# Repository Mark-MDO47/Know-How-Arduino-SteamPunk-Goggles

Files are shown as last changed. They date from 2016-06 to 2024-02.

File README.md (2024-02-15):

# Know-How-Arduino-SteamPunk-Goggles

Adapted from two episodes of TWIT-TV Know How
- Episode 186: https://twit.tv/shows/know-how/episodes/186?autostart=false
- Episode 187: https://twit.tv/shows/know-how/episodes/187?autostart=false

**Table Of Contents**
* [Top](#know\-how\-arduino\-steampunk\-goggles "Top")
* [Pictures](#pictures "Pictures")
* [Attribution](#attribution "Attribution")
* [Software changes from KnowHow](#software-changes-from-knowhow "Software changes from KnowHow")
* [UPDATE:](#update "UPDATE:")
* [FURTHER UPDATE:](#further-update "FURTHER UPDATE:")

## Pictures
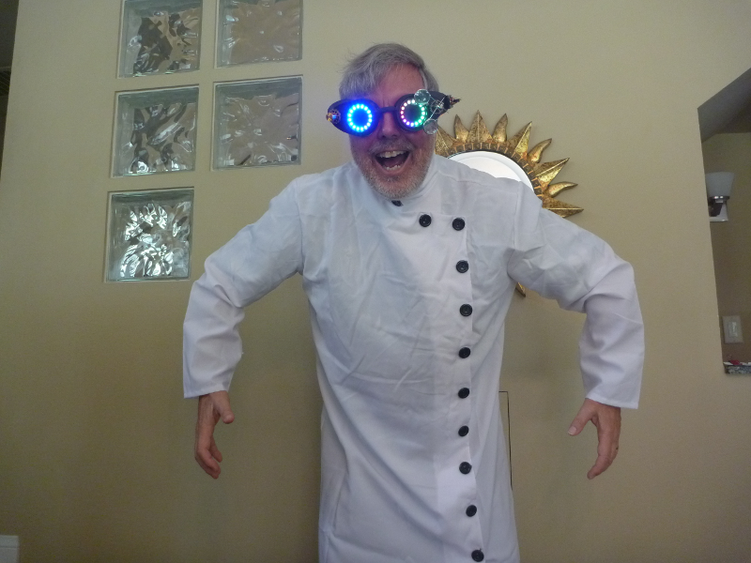
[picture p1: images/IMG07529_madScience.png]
Mad Science is improved when wearing steampunk goggles

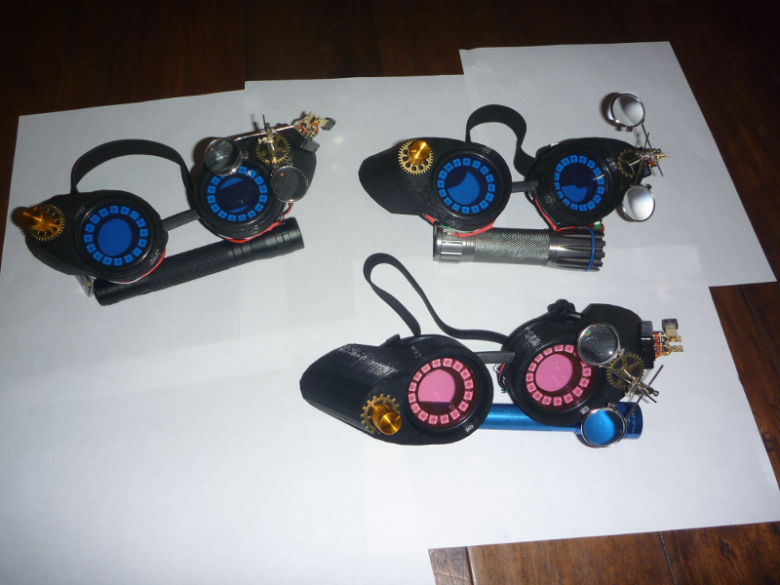
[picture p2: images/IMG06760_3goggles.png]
Built three steampunk goggles - two for friends


## Attribution
Major kudos to Fr. Robert Ballecer and Bryan Burnett for their steampunk goggles project and for pointing me to the FastLED library

Major kudos to Daniel Garcia and Mark Kriegsman for the FANTASTIC FastLED library and examples!!!
https://github.com/FastLED/FastLED

## Software changes from KnowHow

You can see a video of the goggles running through all its patterns at https://youtu.be/VJ-WH86G7Pg

I made one of the potentiometer-selectable patterns cycle or rove through all the patterns one by one.

Then I noticed the code was originally based on some brilliant FastLED patterns that were designed for linear light strips but of course the goggles use two circular rings.

In particular the “sinelon” pattern seemed like it would benefit from remapping the LEDs in a non-linear order. I made the moving light go in a figure-8 pattern between the goggles.

I added a new racetrack” pattern which does two sinelon “cars” moving at slightly different rates.

I also added a “spinner” pattern with four dots per side that spin, and made one side spin back and forth and the other side spin constantly in one direction.

Finally I looked back at other fantastic code samples from FastLED and adapted the “Fire2012” pattern to two circular rings.
https://github.com/FastLED/FastLED/blob/master/examples/Fire2012WithPalette/Fire2012WithPalette.ino

This code is just for fun; not trying to make it an example of how to code in serious applications.

## UPDATE:
See post on TWIT Know-How group in Google Plus: https://plus.google.com/100452347452995185114
See the mention received on TWIT.TV Know-How Episode 225: https://twit.tv/shows/know-how/episodes/225?autostart=false
Thanks Fr. Robert Ballecer and Bryan Burnett for the shout-out!!! Sorry my Google Plus post was such a jaw buster!

Later - Google Plus is no more so that link doesn't work

## FURTHER UPDATE:
For a description of differences between the this build and the KnowHow build (other than software changes above), see
* https://github.com/Mark-MDO47/Know-How-Arduino-SteamPunk-Goggles/blob/master/KnowHowBuildInstructions.md

For a schematic-style wiring diagram of this build, see the KiCad directory or
* https://github.com/Mark-MDO47/Know-How-Arduino-SteamPunk-Goggles/blob/master/SteamPunkGoggles_Wiring.pdf

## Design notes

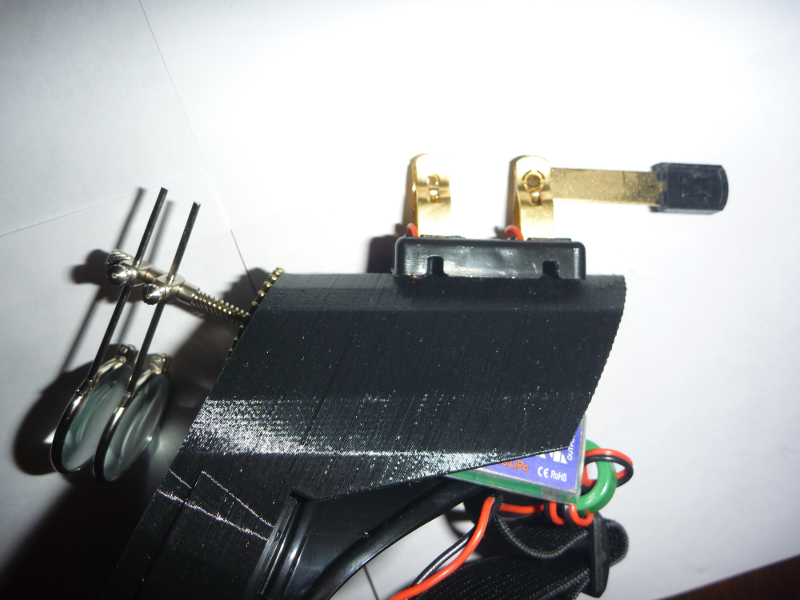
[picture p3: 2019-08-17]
images/IMG06764_detailSwitch.png

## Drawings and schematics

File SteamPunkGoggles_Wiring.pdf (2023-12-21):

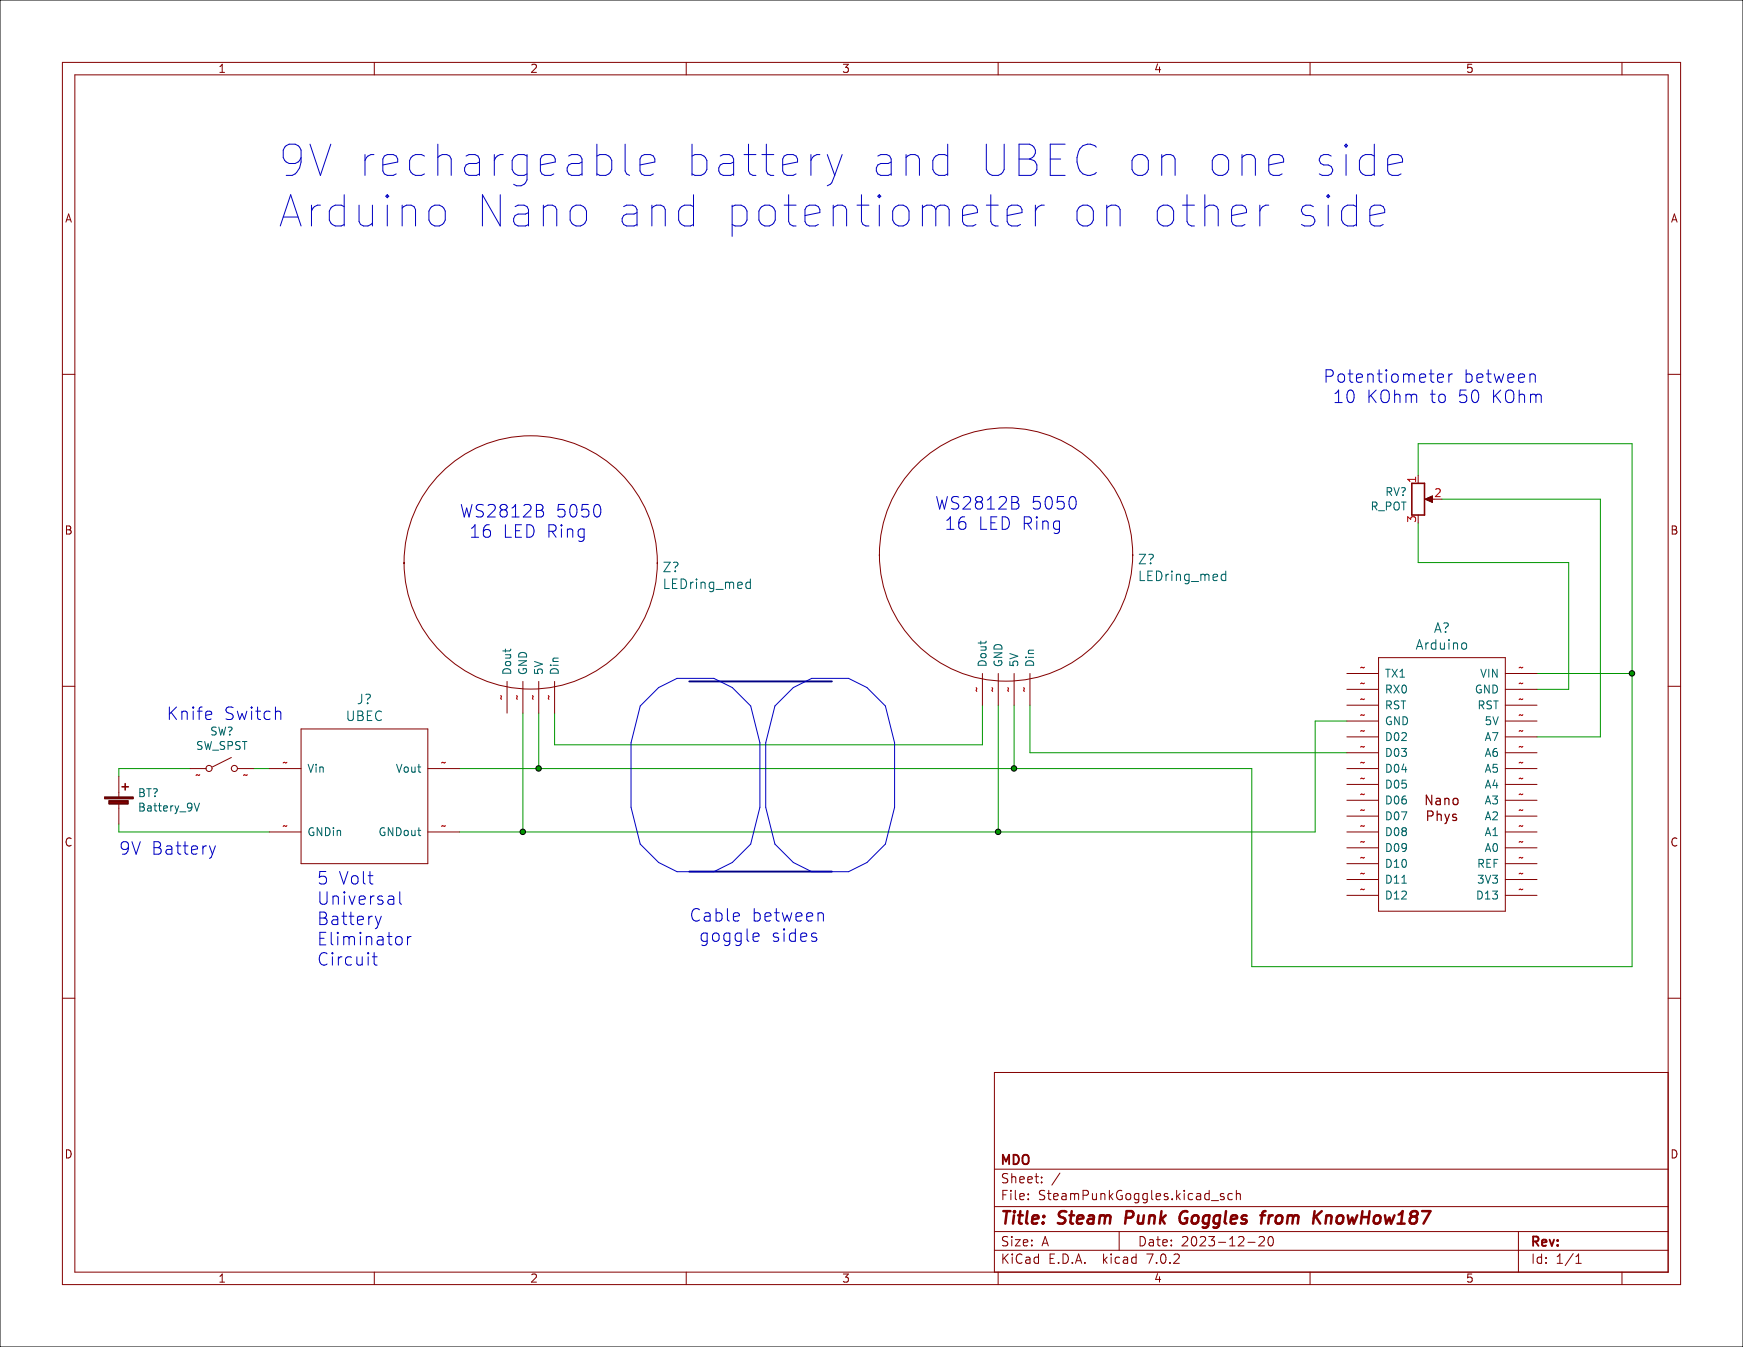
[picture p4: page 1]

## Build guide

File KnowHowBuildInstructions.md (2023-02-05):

# Differences MDO build versus KnowHow build

There are a few differences in my build versus the KnowHow build
- I used a 9V rechargeable battery
- I added a knife switch to power on/off - homage to Frankenstein
- I put all the 5V connections to the Arduino on the 5V pin (no connect for VIN)
- I connected ground to the Arduino REF pin - this gives better performance from the analog input
- I only used one gear for the potentiometer instead of two

Below text is instruction from TWIT-TV KnowHow

# Goggle Wiring Instructions from TWIT-TV Know How 186:

These are the parts you'll need to order for our Steampunk Goggles Build

[MDO - Note that these prices are from 2016]

* Vintage Steampunk Welding Goggles $7.99
* GraceAngie 40Pcs Bronze Alloy Roung Clock Watch gears $6.99
* Magnifying Loupe $6.75
* Arduino Nano (Atmega 328P) $2.19
* WS2812 16-Bit RGB LED Ring ($3.17 x 2) $6.34
* 30AWG Silicone Wire ($1.00 x 3) [Red, Black, Blue] $3.00
* 600mah batteries + Charging harness $18.00

Total $51.26

You'll also need a 3D Printer that can print the following parts
* Steampunk Googles Frame (Right Side)
* Steampunk Goggles Frame (Left Side)
* Steampunk Goggles LED Holder (x2)

Tools and supplies
* 3D Printer
* Dremel (or other drilling tool)
* Hot Glue Gun
* Soldering Kit
* Pliers, Screwdrivers
* Heat Shrink Tubing (Black)

Instructions:
* Disconnect one of the eye cups from the bridge strap
* Drill a small rat hole at the base of each nose-cutout. (Big enough for 6 strands of 30awg silicone wire
* Cut the following pieces of 30awg Silicone Wire -- 2 x 6" Red -- 1 x 8" Red -- 2 x 6" Black -- 1 x 8" Black -- 1 x 6" White -- 1 x 8" White
* Strip and tin all your Silicone wires
* Cut a 3/4" long piece of 1/4" Black Heat Shrink tubing
* Run the 3, 8" lengths through the heat shrink tubing, then push the tubing & wires over the exposed bridge strap
* Reconnect both cups to the bridge strap
* Run the 3, 8" lengths into the left cup rat-hole.
* Solder the following: -- Black to any "GND" pad -- Red to any "VCC" pad -- White to "IN" pad
* Run 1 x 6" black and 1 x 6" red into the left cup rat-hole
* Solder the following: -- Black to the remaining "GND" pad -- Red to the remaining "VCC" pad
* Solder the black and red wires to a battery connector from the charging harness
* Pull back the slack wire from the left cup
* Run the other side of the 8" wires into the rat-hole on the right cup.
* Solder the following: -- Black to any "GND" pad -- Red to any "VCC" pad -- White to the "OUT" pad
* Run the remaining 6" black, red and white wires into the right-cup rat-hole.
* Solder the following: -- Black to the remaining "GND" pad -- Red to the remaining "VCC" pad -- White to the "In" pad
* Solder the other ends of those wires to the Arduino: -- Black to "GND" -- Red to "VIN" -- White to "D3"

# Goggle Integration Instructions from from TWIT-TV Know How 187:

Instructions
* Solder 30awg black/red (ground/voltage) wires to the outside pins of the potentiometer
* Solder a single 30awg blue or white wire to the inside pin of the pot
* Solder the black wire to an arduino GND through-hole
* Solder the red wire to the arduino 5v through-hole
* Solder the blue/white wire to the arduino Analog 7 through-hole
* Insulate your Arduino assembly with a strip of 1-1/4" clear heat-shrink.
* Insert the LED retention rings into each cup, making sure to keep the wires in the cutout
* Install the potentiometer into the 6mm hole in the right cup, lighing up the support peg with the indent
* Shave down the center hole of two brass gears so that they will fit around the pot shaft.
* Place the brass gear over the pot shaft and fasten it with a washer and the mounting nut.
* Insert the right cup into the right-frame, making sure to line up the bridge strap with the cutout in the frame piece, while holding back the wires so that they'll be hidden by the frame.
* Using a piece of double-sided foam tape, secure the arduino to the inside of the right frame. 13. Remove the mounting nut, clips and clip spring from the magnifying loupe.
* Insert the loupe pole through a brass gear, then insert it into the 2mm mounting hole in the left frame.
* Secure the loupe with the mounting nut, tightening it until the loupe lenses are held in tension.
* Run the battery harness through the hole at the bottom of the battery plate in the left frame piece.
* Insert the left cup into the left frame, once again making sure that the wires are covered by the frame.
* Programming We need to add the code that allows us to use the potentiometer to control which animation is being displayed.

Things to Remember
* We're using the "100 lines" code as the basis of our sketch
* We soldered the wiper (the pin that sends variable voltage depending on the position of the pot) to Analog 7
* The data line going to our LED rings is soldered to Digital 3. We have 32 LEDs (16 + 16) [MDO correction pin 3]

Things that we changed in the Code
* DATA_PIN is set to "3"
* NUM_LEDS is set to "32"
* Brightness is set to "100"
* We added "Serial.begin(9600);" to the setup so we can get feedback from the Arduino
* In "loop()", we changed the last line 
  * "EVERY_N_SECONDS( 10 ) { nextPattern();"
* to: -- 
  * "EVERY_N_Seconds ( .5 ) { pattern();"
* By bumping the "EVERY_N_SECONDS" down to .5, it means that the Arduino will call the "pattern()" function ever half-second, instead of checking every 10 seconds
* We created the function "pattern()" to check the status of the Analog pot and turn it into a value that will set "gCurrentPatternNumber" to a value between 0-5
* We added a function and an array entry for blanking the ring.

The "pattern" routine
* void pattern()
* { int aRead = analogRead(7); // This checks the pot connected to Analong Pin 7 and gives us a value between 0-1024
*   int PatChoice = map(aRead, 0, 1020, 0, 6); // This maps the value of the pot from 0-1020 to a value between 0-5
*   Serial.print(aRead); // debug -- Sends the value of the pot to the serial port
*   Serial.print(""\t""); // debug -- Sends a tab
*   Serial.println(PatChoice); // debug -- Sends the remapped value to the serial port, then breaks into a new line
*   gCurrentPatternNumber = PatChoice; // Sent the animation value
* }

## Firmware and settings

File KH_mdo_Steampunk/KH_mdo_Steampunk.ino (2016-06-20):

#include "FastLED.h"

// FastLED "100-lines-of-code" demo reel, showing just a few 
// of the kinds of animation patterns you can quickly and easily 
// compose using FastLED.  
//
// This example also shows one easy way to define multiple 
// animations patterns and have them automatically rotate.
//
// -Mark Kriegsman, December 2014


// The Fire2012 code is based on 2016-06-01 version of
//   https://github.com/FastLED/FastLED/blob/master/examples/Fire2012WithPalette/Fire2012WithPalette.ino

// Mark Olson 2016-06
// adapted from TWIT-TV Know How 187: https://twit.tv/shows/know-how/episodes/187?autostart=false
//     major kudos to Fr. Robert Ballecer and Bryan Burnett for their steampunk goggles project
//             and for pointing me to the FastLED library
//     major kudos to Daniel Garcia and Mark Kriegsman for the FANTASTIC FastLED library and examples!!!
//
// I consider these to be my "mad scientist" goggles...
//
// As in the KH original,  patterns can be selected via the potentiometer. If the potentiometer is set 
//     all the way clockwise, then it "roves" through the patterns (most of them).
// I added a knife-switch on/off control (mad scientist) so I don't use the blank() pattern.
//     Knife switch looks cool!
//
// I adapted the sinelon() pattern to know about the dual-ring LED arrangement; it now does a figure-8
// I added a few patterns; all of them dual-ring aware:
//     racetrack() - like sinelon() but with two non-synchronized "race cars"
//     spinner() - four color spots with RH rotating constant speed and LH rotating back & forth in pattern
//     Fire2012WithPalette() - fire pattern (see Fire2012 above) distributed symmetrically about the nose.
//         When "roving" through the patterns, uses the HEAT color scheme. When pattern statically selected,
//         cycles through color schemes with both sides same scheme (looks better than different schemes).
//         When "roving", both sides move symmetrically around the ring slowly.
//         When pattern statically selected, RH side moves as above but LH side rotating back and forth.

#if FASTLED_VERSION < 3001000
#error "Requires FastLED 3.1 or later; check github for latest code."
#endif

#define DATA_PIN    3
#define LED_TYPE    WS2812
#define COLOR_ORDER GRB
#define NUM_LEDS    32
CRGB leds[NUM_LEDS];

// MDO some more definitions for fancy lights
#define HALF_LEDS (NUM_LEDS/2)
#define QUARTER_LEDS (NUM_LEDS/4)
#define EIGHTH_LEDS  (NUM_LEDS/8)

// MDO analog definitions
#define ANLG_PIN  7
#define ANLG_ROVING 1000 // anything >= this gives the roving pattern

#define BRIGHTNESS         100
#define FRAMES_PER_SECOND  120


#define NUMOF(a) (sizeof((a)) / sizeof(*(a)))

// COOLING: How much does the air cool as it rises?
// Less cooling = taller flames.  More cooling = shorter flames.
// Default 55, suggested range 20-100 
#define COOLING  80

// SPARKING: What chance (out of 255) is there that a new spark will be lit?
// Higher chance = more roaring fire.  Lower chance = more flickery fire.
// Default 120, suggested range 50-200.
#define SPARKING 100

CRGBPalette16 gPal_fire;
CRGBPalette16 gPal_fire_alt;

byte g_alt_use_for_lh = 0; // set to 1 to use alt color scheme and mapping for LH

// choose the fire color scheme
#define FIRE_COLOR_SCHEME_HEAT 1 // the FastLED built-in HeatColors_p
#define FIRE_COLOR_SCHEME_BRW  2 // a simplified three-step gradient, from black to red to white
#define FIRE_COLOR_SCHEME_BRYW 3 // a gradient from black to red to yellow to white
#define FIRE_COLOR_SCHEME_BLUE 4 // a similar gradient, but in blue colors rather than red ones
#define FIRE_COLOR_SCHEME_MDO  5 // Mark's attempt to tune fire colors to his LED rings
#define FIRE_COLOR_SCHEME_GRN  6 // Mark's attempt at a green pattern
#define FIRE_COLOR_SCHEME_DYN  7 // a dynamic palette
#define PLAYFIRE_COLOR_SCHEME_MIN  FIRE_COLOR_SCHEME_BRYW // minimum to cycle through
#define PLAYFIRE_COLOR_SCHEME_MAX  FIRE_COLOR_SCHEME_GRN  // maximum to cycle through inclusive
static uint8_t g_color_scheme = FIRE_COLOR_SCHEME_HEAT; // HEAT is used when roving through patterns
static uint8_t g_color_scheme_alt = FIRE_COLOR_SCHEME_BRYW; // alternate scheme for LH side

// #define DEBUG_MAP // print LED mapping on serial monitor each time the arrangement is set
#define DEBUG_POT // print potentiometer setting on serial monitor each time the arrangement is read

// for symmetry of glasses - two round LED strings
// this mapping can be used with the Fire2012 code and with other effects
static byte g_lin2circ_arrange[NUM_LEDS]; // maps linear index to double circle
static byte g_lin2circ_arrange_alt[NUM_LEDS]; // maps linear index to double circle - alternate copy
static byte g_arrange_sym = 1; // 1 = patterns are symmetrical left-to-right and up-to-down
                        // 0 = patterns same side and same top/bottom on both
static char g_arrange_sym_mult = (1-(g_arrange_sym*2)); // -1 for sym, +1 for same)
static int g_arrange_rotate_modulus = 60; // default how many "show()" between rotates;
static int g_arrange_rot_count = 0; // used if we rotate point of fire
static byte g_arrange_rot_rh = 12; // used if we rotate point of fire; map linear 0 to this
                         // 12 means to "nose" of glasses (20 for LH side)
                         //  8 means top of glasses
                         //  4 means outside of glasses
                         //  0 means bottom of glasses
static byte g_arrange_rot_lh = 20; // used if we rotate point of fire
                        // ((g_arrange_rot_rh + HALF_LEDS - g_arrange_sym * QUARTER_LEDS) % HALF_LEDS)
// #define ARRANGE_CAL_RING // display "red" LED on fire point each time the arrangement is set

// example: g_arrange_sym 1 and g_arrange_rot_rh 12 and g_arrange_rot_lh 20
// in this one fire burns from nose of glasses to edges





void setup() {
  delay(3000); // 3 second delay for recovery
  
  Serial.begin(9600);
  
  // tell FastLED about the LED strip configuration
  FastLED.addLeds<LED_TYPE,DATA_PIN,COLOR_ORDER>(leds, NUM_LEDS).setCorrection(TypicalLEDStrip);
  //FastLED.addLeds<LED_TYPE,DATA_PIN,CLK_PIN,COLOR_ORDER>(leds, NUM_LEDS).setCorrection(TypicalLEDStrip);

  // set master brightness control
  FastLED.setBrightness(BRIGHTNESS);

  // initialize the linear to circular mapping
  init_lin2circ_arrange(g_lin2circ_arrange, g_arrange_rot_lh, g_arrange_rot_rh, g_arrange_sym, g_arrange_sym_mult);

  // initialize the Fire palette
  Fire2012WithPalette_setup(gPal_fire, g_color_scheme);
} // end setup()


// List of patterns to cycle through.  Each is defined as a separate function below.
typedef void (*SimplePatternList[])();
SimplePatternList gPatterns = { blank, rainbow, spinner, rainbowWithGlitter, confetti, sinelon, juggle, bpm, Fire2012WithPalette, racetrack };

uint8_t gCurrentPatternNumber = 0; // Index number of which pattern is current
uint8_t gRovingPatternNumber = 0; // MDO roving pattern number if roving selected
uint16_t gRovingCount = 0; // MDO roving count to change
uint8_t g_IamRovingThePattern = 0; // MDO - =1 if we are roving the pattern
uint8_t gHue = 0; // rotating "base color" used by many of the patterns
  
void loop()
{
  // Call the current pattern function once, updating the 'leds' array
  gPatterns[gCurrentPatternNumber]();

  // send the 'leds' array out to the actual LED strip
  FastLED.show();  
  // insert a delay to keep the framerate modest
  FastLED.delay(1000/FRAMES_PER_SECOND); 

  // do some periodic updates
  EVERY_N_MILLISECONDS( 10 ) { gHue++; } // slowly cycle the "base color" through the rainbow
  EVERY_N_SECONDS( .5 ) { pattern(); } // change patterns periodically
} // end loop()

void pattern()
{
  int aRead = analogRead(ANLG_PIN); // This checks the pot connected to Analog Pin 7 and gives us a value between 0-1024
  // MDO note: we have on/off switch so don't need zero. Leave in place though
  int PatChoice = map(aRead, 0, ANLG_ROVING, 1, NUMOF(gPatterns)); // This maps the value of the pot from 0-1023 to a value between 1 to last pattern num
  g_IamRovingThePattern = 0;
  if (aRead > (ANLG_ROVING-1)) 
  { // MDO fixes some oscillation at the high end
    g_IamRovingThePattern = 1;
    PatChoice = gRovingPatternNumber + 2;
  }

#ifdef DEBUG_POT
  Serial.print(aRead); // debug -- Sends the value of the pot to the serial port
  Serial.print("\t");  // debug -- Sends a tab
  Serial.println(PatChoice);  // debug -- Sends the remapped value to the serial port, then breaks into a new line
#endif // DEBUG_POT

  gCurrentPatternNumber = PatChoice; // Set the animation value
  rove_pattern();

  // rotate the linear to circular fire points
  loop_lin2circ_arrange();

}  // end pattern()

void rove_pattern() // MDO rove through pattern numbers
{
  gRovingCount += 1;
  if (gRovingCount >=511)
  {
    gRovingCount = 0;
    gRovingPatternNumber = ((gRovingPatternNumber + 1) % (NUMOF(gPatterns)-2)); // MDO +2 to get a pattern
    // rainbow and rainbow with glitter are so close just doing glitter
  }
} // end rove_pattern()

static uint32_t mdoResetTime = 0;

uint32_t mdo_millisecond_timer()
{
  return millis() - mdoResetTime;
} // end mdo_millisecond_timer()

void mdo_millisecond_timer_reset()
{
  mdoResetTime = millis();
} // end mdo_millisecond_timer_reset()

void blank()
{
  fadeToBlackBy( leds, NUM_LEDS, 20); // This gives the goggles an "off" position
} // end blank()

void rainbow()
{
  // FastLED's built-in rainbow generator
  fill_rainbow( leds, NUM_LEDS, gHue, 7);
} // end rainbow()

void rainbowWithGlitter() 
{
  // built-in FastLED rainbow, plus some random sparkly glitter
  rainbow();
  addGlitter(80);
} // end rainbowWithGlitter()

void addGlitter( fract8 chanceOfGlitter) 
{
  if( random8() < chanceOfGlitter) {
    leds[ random16(NUM_LEDS) ] += CRGB::White;
  }
} // end addGlitter()

void confetti() 
{
  // random colored speckles that blink in and fade smoothly
  fadeToBlackBy( leds, NUM_LEDS, 10);
  int pos = random16(NUM_LEDS);
  leds[pos] += CHSV( gHue + random8(64), 200, 255);
} // end confetti()

void sinelon()
{
  // a colored dot sweeping back and forth, with fading trails
  // Mark Olson 2016-05 - make it do figure-8 by using calcpos_figure8
  fadeToBlackBy(leds, NUM_LEDS, 20);
  int pos = beatsin16(13,0,4*NUM_LEDS);
  pos = calcpos_figure8(pos);
  leds[pos] += CHSV( gHue, 255, 192);
} // end sinelon()

// Mark Olson 2016-05
//   racetrack shows two "cars" racing on a figure-8 racetrack
//   The two cars are out of sync with each other so effect appears
//   chaotic (although actually predictable)
void racetrack()
{
  // clear the screen a bit so not too busy
  fadeToBlackBy(leds, NUM_LEDS, 120);
  
  int pos = beatsin16(13,0,4*NUM_LEDS);
  pos = calcpos_figure8(pos);
  leds[pos] += CHSV( gHue, 255, 192);

  pos = beatsin16(14,0,4*NUM_LEDS);
  pos = calcpos_figure8(pos);
  leds[pos] += CHSV( gHue+128, 255, 192);
} // end racetrack()

int calcpos_figure8(int pos)
{
  // Mark Olson 2016-05
  //   tilt both circles 1/4 but in opposite directions
  //   used to make figure 8 for racetrack
  // a different implementation can be found in the routines with lin2circ in the name
  pos %= NUM_LEDS;
  if (pos >= HALF_LEDS) {
    pos = (pos - EIGHTH_LEDS) % HALF_LEDS;
    pos = NUM_LEDS - 1 - pos;
  } else {
    pos =(pos + 3*EIGHTH_LEDS - 1) % HALF_LEDS;
  }
  return(pos);
} // end calcpos_figure8()


static int g_spin_color_mode = 3; // 0=simple, 1=lava, 2=party, 3=party/lava
CRGB spin_colors(byte iter, int led)
{
  // Mark Olson 2016-05
  // used by the spinner routine to cycle through colors
  // I should probably get my act together and merge all the palettes, but I
  //    have not run out of memory yet...
  static CRGB some_spin_colors[4] = { CRGB::White, CRGB::Red, CRGB::Navy, CRGB::Green };
  static CRGBPalette16 party_palette = PartyColors_p;
  static CRGBPalette16 lava_palette = LavaColors_p;

  int my_spin_color_mode = g_spin_color_mode;
  if (my_spin_color_mode >= 3) {
    my_spin_color_mode -= (led/HALF_LEDS) + 1;
  }

  switch (my_spin_color_mode) {
    case 1: // lava
      return ColorFromPalette(lava_palette, gHue-led+(iter*59), led-gHue+(iter*59));
      break;
    case 2: // party
      return ColorFromPalette(party_palette, gHue-led+(iter*59), led-gHue+(iter*59));
      break;

    default:
    case 0: // simple
      return some_spin_colors[iter & 0x3];
      break;
  }
} // end spin_colors()

#define SPIN_INTERVAL 4
void spinner()
{
  // Mark Olson 2016-05
  //   this puts four dots on the screen and spins them
  //   the right hand side goes clockwise at constant speed
  //   the left hand side goes back and forth at varying speed

  // clear the screen a bit so not too busy
  fadeToBlackBy(leds, NUM_LEDS, 100);

  int pos1 = (mdo_millisecond_timer() / 50) & 511;
  int pos2 = beatsin16(13,0,64);

  byte dothue = 0;
  int tmp = 0;
  for (int i = 0; i < HALF_LEDS; i += SPIN_INTERVAL)
  {
     tmp = (pos1+i) % HALF_LEDS;
     leds[tmp] |= spin_colors(dothue, tmp);
     // dothue += 32;
     tmp = (pos2+i+SPIN_INTERVAL/2) % HALF_LEDS;
     tmp = HALF_LEDS-tmp-1; // reverse direction
     leds[tmp+HALF_LEDS] |= spin_colors(dothue, tmp+HALF_LEDS);
     dothue += 1;
  }
} // end spinner()

void bpm()
{
  // colored stripes pulsing at a defined Beats-Per-Minute (BPM)
  uint8_t BeatsPerMinute = 62;
  CRGBPalette16 palette = PartyColors_p;
  uint8_t beat = beatsin8( BeatsPerMinute, 64, 255);
  for( int i = 0; i < NUM_LEDS; i++) { //9948
    leds[i] = ColorFromPalette(palette, gHue+(i*2), beat-gHue+(i*10));
  }
} // end bpm()

void juggle() {
  // eight colored dots, weaving in and out of sync with each other
  fadeToBlackBy( leds, NUM_LEDS, 20);
  byte dothue = 0;
  for( int i = 0; i < 8; i++) {
    leds[beatsin16(i+7,0,NUM_LEDS)] |= CHSV(dothue, 200, 255);
    dothue += 32;
  }
} // end juggle()

// Linear to Dual-Circular mapping - Mark Olson 2016-06
//
// My LED rings are arranged so that (from the front) LED 0 is on the bottom and the
//    numbering increases as you go clockwise. The right hand ring has numbers 0-15
//    and the left hand ring has numbers 16-31. I take care to make RH 4 match up
//    with LH 20 (both near the nose).
//
// To map the fire simulation linear string to my goggles, the approach is as follows:
//      distribute the fire points between left and right rings. within a ring, distribute
//      points first on one side then the other to cover the ring (for instance) from
//      bottom to top.
//    g_arrange_sym can be 1 (mirror image left-right and top-bottom between the two circles)
//                    or 0 (same geometry for both circles)
//      When the fire point is touching the nose it looks best to have symmetry set to 1.
//         If the fire point is on the bottom, best to have symmetry 0
//         since otherwise on the LH side fire point will be on the top.
//    For the case in which the two fire points on the goggles are at the bottom and symmetry 0:
//      linear 0 (fire bottom) maps to RH bottom (led 0)
//      linear 1 maps to LH bottom (led 16)
//      linear 2 maps to RH bottom off to one side (led 1)
//      linear 3 maps to LH bottom off to one side (led 1)
//      The complete mapping from from linear to dual-circular for start 0 sym 0 is shown here:
//  0 16 1 31 15 17 2 30 14 18 3 29 13 19 4 28 12 20 5 27 11 21 6 26 10 22 7 25 9 23 8 24 
//      The complete mapping from from linear to dual-circular for start 12 sym 1 is shown here:
//  12 20 13 19 11 21 14 18 10 22 15 17 9 23 0 16 8 24 1 31 7 25 2 30 6 26 3 29 5 27 4 28 
//      
//      '#define DEBUG_MAP' to print LED mapping on serial monitor each time the arrangement is set
//      '#define ARRANGE_CAL_RING' to display "red" LED on fire point each time the arrangement is set
void init_lin2circ_arrange(byte * lin2circ_arrange, char arrange_lh, char arrange_rh, char arrange_sym, char arrange_sym_mult)
{
  // This routine initializes an array to account for symmetry of two ring LED strips in glasses
  // un-arranged 12 is approx nose-near for RH side, 20 is approx nose-near for LH side
  byte led;
  static char delta_array[4] = { -1, +1, +1, -1 };

  // if doing rotating point of fire, save current location
  g_arrange_rot_lh = arrange_lh;
  g_arrange_rot_rh = arrange_rh;

  // if NOT calibrating ring, distribute LEDs from linear to dual-circular
#ifndef ARRANGE_CAL_RING
  lin2circ_arrange[0] = arrange_rh % HALF_LEDS;
  lin2circ_arrange[1] = arrange_lh % HALF_LEDS;
  lin2circ_arrange[2] = (lin2circ_arrange[0] + 1) % HALF_LEDS;
  // convert to (int) so can support up to 255 LEDs
  lin2circ_arrange[3] = (HALF_LEDS + ((int) lin2circ_arrange[1]) - 1) % HALF_LEDS;
  for (led = 4; led < NUM_LEDS; led += 1)
  {
    // convert to (int) so can support up to 255 LEDs
    lin2circ_arrange[led] = (HALF_LEDS + (((int) lin2circ_arrange[led-4]) )+ delta_array[led % 4]) % HALF_LEDS;
  }
#else // ARRANGE_CAL_RING - we are calibrating rings; just show fire point
  for (led = 0; led < NUM_LEDS; led += 2)
  {
    lin2circ_arrange[led+0] = arrange_rh % HALF_LEDS;
    lin2circ_arrange[led+1] = arrange_lh % HALF_LEDS;
  }
#endif // ARRANGE_CAL_RING

  // left hand ring has odd-numbered entries
  for (led = 1; led < NUM_LEDS; led += 2)
  {
    lin2circ_arrange[led] += HALF_LEDS; // left-hand side
  }

#ifdef DEBUG_MAP // here to print out our mapping table
  for (led = 0; led < NUM_LEDS; led += 1)
  {
    Serial.print(" ");
    Serial.print(lin2circ_arrange[led]);
  }
  Serial.println(" ");
#endif // DEBUG_MAP
} // end init_lin2circ_arrange()

// Mark Olson 2016-06 - mixed in with playing with fire color scheme rotation
//  this is all a big hack but I haven't gone back to clean it up
void loop_lin2circ_arrange()
{
  // If desired, rotate our point of fire within linear to dual-circular mapping
  // g_arrange_rotate_modulus=1 gives fastest rotation
  // g_arrange_rotate_modulus=0 gives no rotation but still defines the code

  static byte count_rotates = 0; // to slow down color changes
  #define COLOR_CHANGE_FIRE_MODU 5 // change every five moves of fire point (rotates colors around)

  byte my_arrange_rot_rh = g_arrange_rot_rh; // save values so don't overwrite
  byte my_arrange_rot_lh = g_arrange_rot_lh; // save values so don't overwrite
  byte pos_rh = beatsin16(13,0,HALF_LEDS); // 128 is well within 255
  if ((1 == g_alt_use_for_lh) && (pos_rh != g_lin2circ_arrange_alt[0]))
  {
    byte pos_lh = (pos_rh + HALF_LEDS - g_arrange_sym * QUARTER_LEDS) % HALF_LEDS;
    init_lin2circ_arrange(g_lin2circ_arrange_alt, pos_lh, pos_rh, g_arrange_sym, g_arrange_sym_mult);
  }
  g_arrange_rot_rh = my_arrange_rot_rh;
  g_arrange_rot_lh = my_arrange_rot_lh;

  g_arrange_rot_count = (g_arrange_rot_count + 1) % g_arrange_rotate_modulus;
  if (g_arrange_rot_count == 0)
  {
    g_arrange_rot_rh = (g_arrange_rot_rh + 1) % HALF_LEDS;
    g_arrange_rot_lh = (g_arrange_rot_lh + g_arrange_sym_mult + HALF_LEDS) % HALF_LEDS;
    init_lin2circ_arrange(g_lin2circ_arrange, g_arrange_rot_lh, g_arrange_rot_rh, g_arrange_sym, g_arrange_sym_mult);
    count_rotates = (count_rotates + 1) % COLOR_CHANGE_FIRE_MODU;
    if ((0 == g_IamRovingThePattern) && (0 == count_rotates))
    {
      // initialize the Fire palette
      g_color_scheme += 1;
      if (g_color_scheme > PLAYFIRE_COLOR_SCHEME_MAX) { g_color_scheme = PLAYFIRE_COLOR_SCHEME_MIN; }
      Fire2012WithPalette_setup(gPal_fire, g_color_scheme);
      // and for the left-hand side
      g_color_scheme_alt += 1;
      if (g_color_scheme_alt > PLAYFIRE_COLOR_SCHEME_MAX) { g_color_scheme_alt = PLAYFIRE_COLOR_SCHEME_MIN; }
      Fire2012WithPalette_setup(gPal_fire_alt, g_color_scheme_alt);
    }
  }
} // end loop_lin2circ_arrange()


// the work is all done - here we just do the translation
byte getpixnum_lin2circ(byte inpnum)
{
  if ((0 == g_alt_use_for_lh) || (0 == (inpnum & 1)))
  {
    return(g_lin2circ_arrange[inpnum]);
  }
  else
  {
    return(g_lin2circ_arrange_alt[inpnum]);
  }
} // end getpixnum_lin2circ()





// Fire2012 with programmable Color Palette
//
// This code is the same fire simulation as the original "Fire2012",
// but each heat cell's temperature is translated to color through a FastLED
// programmable color palette, instead of through the "HeatColor(...)" function.
//
// Four different static color palettes are provided here, plus one dynamic one.
// 
// The three static ones are: 
//   1. the FastLED built-in HeatColors_p -- this is the default, and it looks
//      pretty much exactly like the original Fire2012.
//
//  To use any of the other palettes below, just "uncomment" the corresponding code.
//
//   2. a gradient from black to red to yellow to white, which is
//      visually similar to the HeatColors_p, and helps to illustrate
//      what the 'heat colors' palette is actually doing,
//   3. a similar gradient, but in blue colors rather than red ones,
//      i.e. from black to blue to aqua to white, which results in
//      an "icy blue" fire effect,
//   4. a simplified three-step gradient, from black to red to white, just to show
//      that these gradients need not have four components; two or
//      three are possible, too, even if they don't look quite as nice for fire.
//
// The dynamic palette shows how you can change the basic 'hue' of the
// color palette every time through the loop, producing "rainbow fire".
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

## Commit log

2023-01-28 adding schematic
    [SteamPunkGoggles.kicad_pcb, SteamPunkGoggles.sch]
2023-01-28 update schematic
    [SteamPunkGoggles.sch]
2023-01-28 add wiring instructions
2023-01-28 some KiCad working files
2023-01-28 a schematic file; maybe not needed
2023-01-28 point to build instructions and wiring diagram
2023-02-04 annotate schematic
    [SteamPunkGoggles.sch]
2023-12-21 update to KiCad 7 and use VIN instead of 5V pin
    [SteamPunkGoggles.kicad_sch, SteamPunkGoggles.sch]
2023-12-21 use VIN instead of 5V pin
2023-12-21 minor touch-up for KiCad V7.x
    [SteamPunkGoggles.kicad_sch]
